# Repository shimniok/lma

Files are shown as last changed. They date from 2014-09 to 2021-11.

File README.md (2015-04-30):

lma
===
Lost Model Alarm for finding your lost aircraft.

[User Guide](https://github.com/shimniok/lma/blob/master/firmware/UserGuide.md)

Ultra Micro park flyer planes like the Hobbyzone Champ or Parkzone UM Corsair are light (~40g) and could be blown downwind and out of sight. That's what happened to my Champ.

LMA's on the market usually have 3-pin servo connectors but these RTF planes don't have a place to plug them.

So I decided to make an ultra-light, standalone LMA. Here it is in its various versions along with firmware.

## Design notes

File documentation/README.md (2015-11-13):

# The umlma User Guide

Lost your aircraft? Don't panic; wait for the beeps! After the *SOS Timer* expires, the Ultra-Micro Lost Model Alarm (umlma) beeps SOS every 10 seconds for many hours until you find your missing aircraft.

Also, umlma beeps W in Morse code after a preset *Flight Timer* expires to remind you to land and recharge your aircraft battery.

Want one? [Buy now on Tindie](https://www.tindie.com/products/bot_thoughts/lost-model-alarm/)

##Features
  * Beeps W to warn you to land and recharge
  * Beeps SOS to help you find your lost plane
  * Configurable *Flight Timer* (5, 10, ... 30 minutes) and *SOS Timer*
  * Ultra light, less than 4g with battery
  * Super-efficient 1mA buzzer delivers 80dbA @ 10cm
  * Powered by compact CR1225 battery with low battery warning

##Powering Up
  * Install a CR1225 battery if one isn't installed yet
  * Short the SWITCH pin headers with supplied shorting block
  * After power up, umlma checks the battery voltage and beeps status (see below)

| Beep | Text | Description |
| --- | --- | --- |
| --- -.- | OK | Battery voltage ok |
| ...---... | SOS | Time to get a new CR1225 battery |

* dit = .
* dah = -

###Voltage Calibration
The umlma is calibrated for the low voltage threshold of ~2.5V after being assembled. The firmware performs auto-calibration on initial startup.

##How It Works
Typical RC plane batteries support flight times from 5-15 minutes and running your LiPo battery down too low will ruin it.

After the *Flight Timer* expires, umlma will start beeping W in Morse Code every 10 seconds to warn you it is time to land.

If you lose your plane, the umlma will start to beep SOS in Morse Code after the *SOS Timer* expires. The *SOS Timer* is automatically set to twice the value of the *Flight Timer*

| Beep | Text | Description |
| --- | --- | --- |
| .-- | W | Flight time warning, time to land |
| ...---... | SOS | Listen for this when looking for your lost plane |

* dit = .
* dah = -

##Setting the Flight Timer
It's easy to configure the *Flight Timer*. 

1. Hold down the pushbutton switch while powering on
2. The umlma will beep out the current Flight Timer (as in the table below)
  * If the current *Flight Timer* is what you want, release the button
  * Or, to increment the timer, keep holding the button another 3 seconds
3. umlma will increment the *Flight Timer* by 5 minutes
4. go to 2.

| Beep | Flight Timer | SOS Timer |
| --- | --- | --- |
| . | 5m | 10m |
| - | 10m | 20m |
| -. | 15m | 30m |
| -- | 20m | 40m |
| --. | 25m | 50m |
| --- | 30m | 60m |

* dit = .
* dah = -

##Recovery
###How Long Does It Beep?
The umlma is designed with the optimum tradeoffs between weight, size, and battery life. The umlma is designed to conserve as much battery power as possible to be devoted to recovery. A new battery should continue beeping for at least 10 hours, based on theoretical calculations. Temperature and battery age and construction will affect its longevity.

###How Loud Is It?
Because of weight and size constraints, the umlma uses a CR1225 battery and 
small, efficient buzzer which delivers 80dBA @ 10cm.  As a result, there is a
limit to how close you have to be to the umlma to hear it beeping.  Consider
getting help from a younger person with better hearing. :)
  
##Larger Battery
Instead of the CR1225, you can connect a larger battery to the VCC (positive) and GND (ground) pins on the board. 

A dedicated battery is best. If you lose your plane after running the flight battery down, there will still be power to run the umlma.

##Remote Switch
If you mount your UMLMA inside your plane, you can install an extension wire from the SWITCH pins to a remote switch outside the plane.

## Questions or Problems?
Contact me (Michael Shimniok) at http://www.bot-thoughts.com for more help

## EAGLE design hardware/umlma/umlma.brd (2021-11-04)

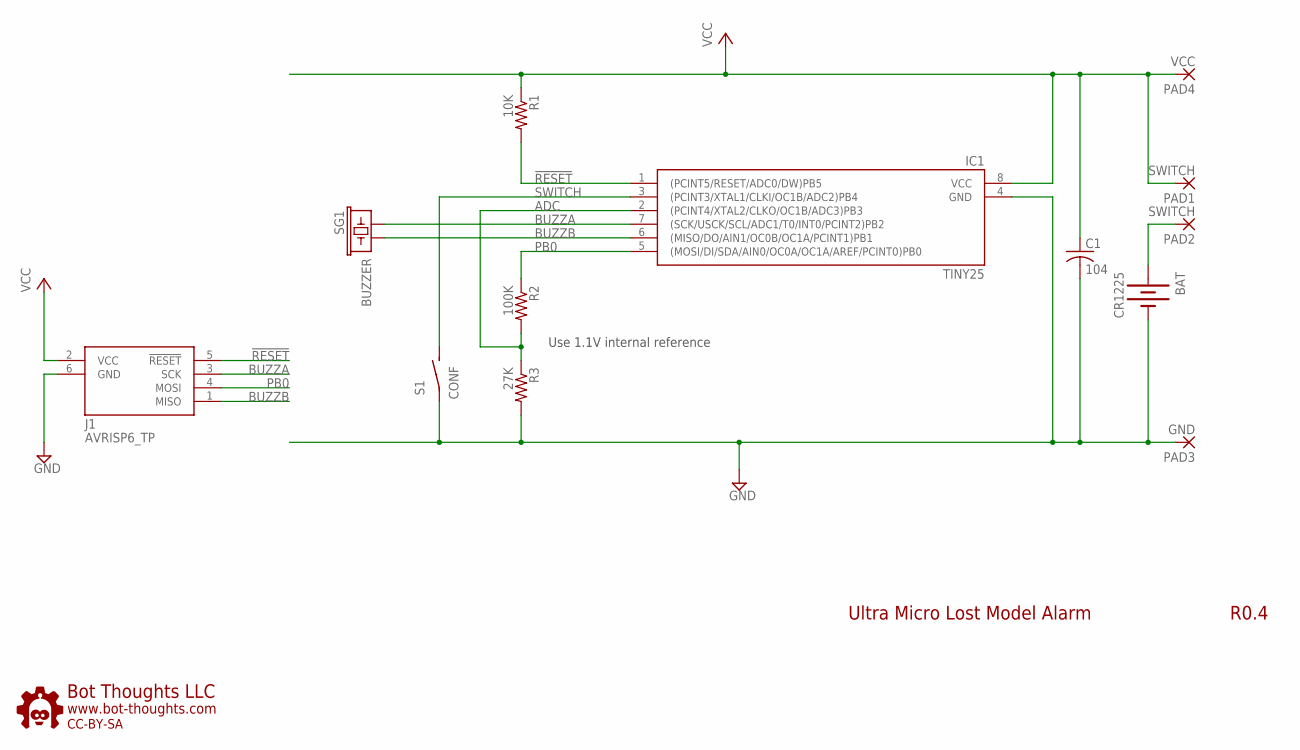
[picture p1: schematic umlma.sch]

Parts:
BAT: CR1225; BATTCON_12MM_PTH
C1: 104; C0603K; PARTNO GRM188R60J105KA01D
IC1: TINY25; SOIC8N
J1: AVRISP6_TP; 2X3_TP
PAD1, PAD2: SWITCH; 1,6/0,8
PAD3: GND; 1,6/0,8
PAD4: VCC; 1,6/0,8
R1: 10K; R0603; PARTNO ERJ-3GEYJ102V
R2: 100K; R0603; PARTNO ERJ-3GEYJ102V
R3: 27K; R0603; PARTNO ERJ-3GEYJ102V
S1: CONF; 3X4X2TACT
SG1: BUZZER; BUZZER_14MM_V_PTH; PARTNO AT-1438-TWT-R
U$1: BTLOGO-LOGO-SM; BTLOGOS

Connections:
!RESET: IC1.1 ((PCINT5/RESET/ADC0/DW)PB5), J1.5 (!RESET), R1.2
ADC: IC1.2 ((PCINT4/XTAL2/CLKO/OC1B/ADC3)PB3), R2.2, R3.1
BUZZA: IC1.7 ((SCK/USCK/SCL/ADC1/T0/INT0/PCINT2)PB2), J1.3 (SCK), SG1.P$5 (1)
BUZZB: IC1.6 ((MISO/DO/AIN1/OC0B/OC1A/PCINT1)PB1), J1.1 (MISO), SG1.P$6 (2)
GND: BAT.GND (-), C1.2, IC1.4 (GND), J1.6 (GND), PAD3.1, R3.2, S1.P$1
unnamed: BAT.VCC@1 (+), PAD2.1
PB0: IC1.5 ((MOSI/DI/SDA/AIN0/OC0A/OC1A/AREF/PCINT0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), J1.4 (MOSI), R2.1
SWITCH: IC1.3 ((PCINT3/XTAL1/CLKI/OC1B/ADC2)PB4), S1.P$2 (S)
VCC: C1.1, IC1.8 (VCC), J1.2 (VCC), PAD1.1, PAD4.1, R1.1

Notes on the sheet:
Ultra Micro Lost Model Alarm
R0.4
Use 1.1V internal reference

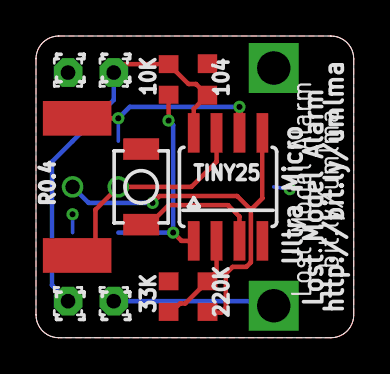
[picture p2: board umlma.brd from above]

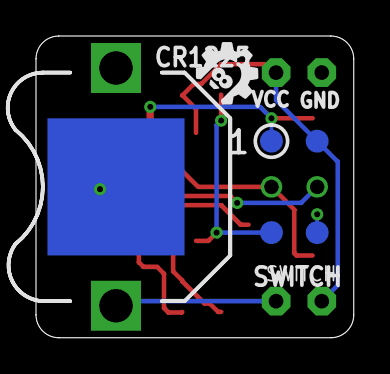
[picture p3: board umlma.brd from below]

Board: 2 copper layers, 17.7 x 16.8 mm, 14 parts (3 on the bottom side), 9 nets.

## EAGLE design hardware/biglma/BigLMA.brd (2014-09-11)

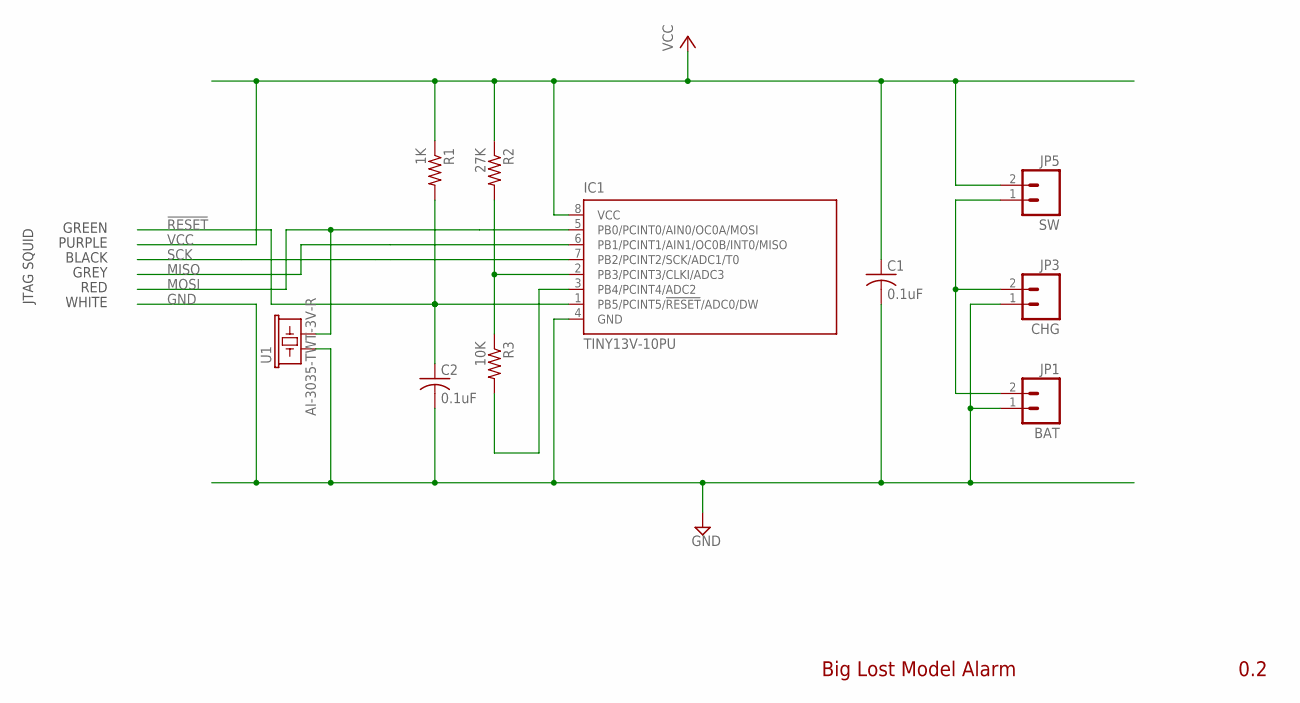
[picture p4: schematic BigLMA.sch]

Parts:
C1, C2: 0.1uF; C0603; PARTNO GRM188R60J105KA01D
IC1: TINY13V-10PU; DIL08; PARTNO ATTINY13V-10PU
JP1: BAT; JST-2-PTH
JP3: CHG; 1X02
JP5: SW; 1X02
R1: 1K; R0603; PARTNO ERJ-3GEYJ102V
R2: 27K; R0603; PARTNO RR0816P-273-D
R3: 10K; R0603; PARTNO RR0816P-103-D
U1: AI-3035-TWT-3V-R; BUZZER-30MM_PTH; PARTNO AI-3035-TWT-3V-R

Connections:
!RESET: C2.1, IC1.1 (PB5/PCINT5/!RESET!/ADC0/DW), R1.2
GND: C1.2, C2.2, IC1.4 (GND), JP1.1, JP3.1, U1.P$1 (1)
MISO: IC1.6 (PB1/PCINT1/AIN1/OC0B/INT0/MISO)
MOSI: IC1.5 (PB0/PCINT0/AIN0/OC0A/MOSI), U1.P$2 (2)
unnamed: IC1.2 (PB3/PCINT3/CLKI/ADC3), R2.2, R3.1
unnamed: JP1.2, JP3.2, JP5.1
unnamed: IC1.3 (PB4/PCINT4/ADC2), R3.2
SCK: IC1.7 (PB2/PCINT2/SCK/ADC1/T0)
VCC: C1.1, IC1.8 (VCC), JP5.2, R1.1, R2.1

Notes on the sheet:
WHITE
RED
GREY
BLACK
PURPLE
GREEN
JTAG SQUID
Big Lost Model Alarm
0.2

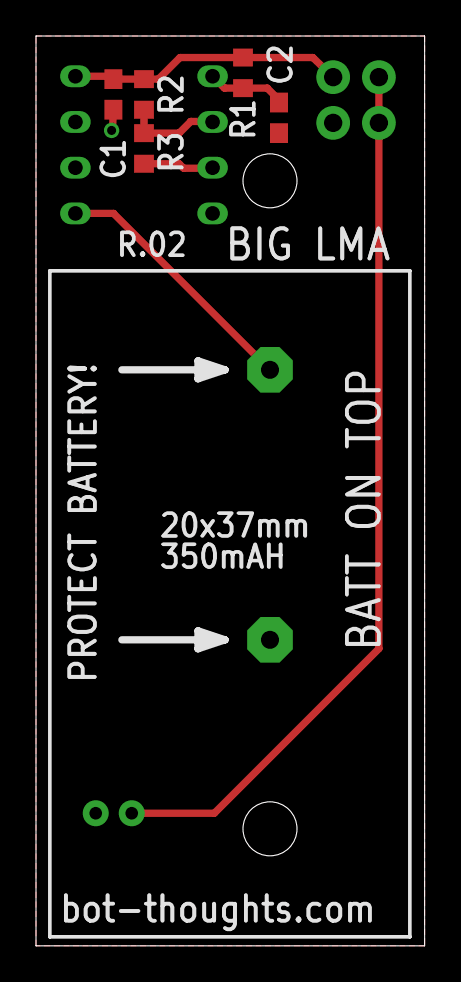
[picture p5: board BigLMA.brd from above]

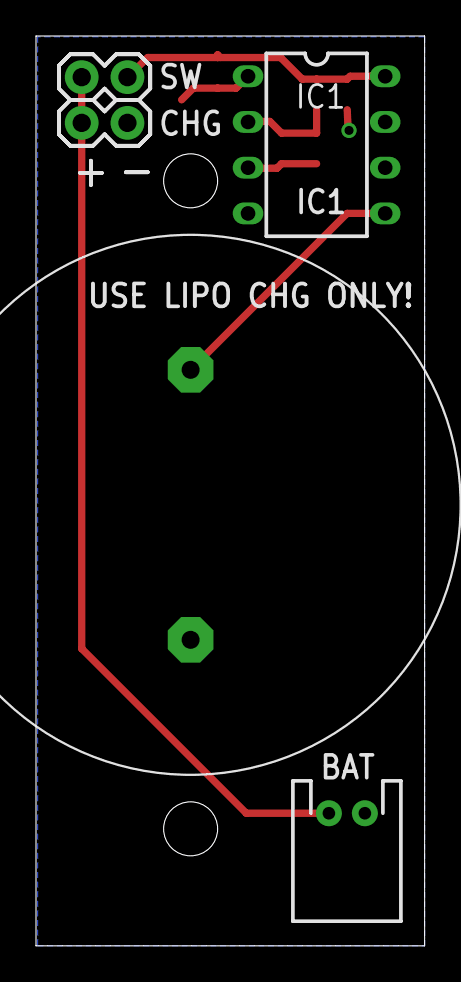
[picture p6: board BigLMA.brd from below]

Board: 2 copper layers, 21.6 x 50.5 mm, 11 parts (5 on the bottom side), 7 nets.

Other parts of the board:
U$1: LIPO_20X37

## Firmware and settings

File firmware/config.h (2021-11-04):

#ifndef _CONFIG_H
#define _CONFIG_H

//#define DEBUG 1

#define BUZZA   PB1     // ATtiny25 Pin 6
#define BUZZB   PB2     // ATtiny25 Pin 7
#define SWITCH  PB4     // ATtiny25 Pin 3
#define LED     PB0     // ATtiny25 Pin 5
#define ADC     PB3     // ATtiny25 Pin 2
#define ADC_EN  PB0     // ATtiny25 Pin 5

#define WARN_PERIOD      10   // Delay period between signal (seconds) -- initial period
#define WARN_PERIOD_LOW  60   // If battery voltage is low, use longer period between beeps
#define BATT_PERIOD     600   // Time in seconds between checking battery voltage

#endif

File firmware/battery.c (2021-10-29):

#include "config.h"
#include "clock.h"
#include <avr/io.h>
#include <util/delay.h>
#include <avr/eeprom.h>
#include "battery.h"

/** battery.c
 *
 * The lma warns the user on startup when the battery falls below ~2.5V
 *
 * Circuit
 * -------
 * The lma is set up to feed a voltage divider with one pin (PB0), and read the divided
 * value with the other (PB3, ADC3). We have to use the internal voltage reference.
 * which varies from 1.0V to 1.2V. Also, the resistors in the divider are 5% tolerance.
 *
 * Calibration
 * -----------
 * That's a pretty huge error which requires calibration. Automatic calibration is
 * done when the lma first starts up (in initADC()) after its eeprom is erased
 * (set to 0).
 *
 * To calibrate, it reads the current voltage, which must be set to 5.0V (within 1%)
 * The adc value returned is 2x that of the 2.5V threshold.  So to get the 2.5V ADC
 * value, right shift the result, then store store it in the threshold eeprom location.
 *
 * Next time initADC() is called, it'll read the threshold and use that.
 *
 * Using
 * -----
 * To erase the calibration, just recompile, and program the eeprom with the .eep file
 * generated at compile time.
 *
 * Note that we want to preserve EEPROM so set Fuses EESAVE and BODLEVEL=1.8V
 */

EEMEM uint16_t cfg_threshold = 0;	// create .eep with this loc initialized to 0.
static uint16_t threshold = 0;      // threshold

uint8_t pinToMux(uint8_t pin) {
	uint8_t mux = 0;
	switch (pin) {
		case PB5: // ADC0
			mux = 0b0000;
			break;
		case PB2: // ADC1
			mux = 0b0001;
			break;
		case PB4: // ADC2
			mux = 0b0010;
			break;
		case PB3: // ADC3
			mux = 0b0011;
			break;
	}
	return mux;
}

void init_battery_thresh() {
	// Read the threshold ADC value for low battery warning
	threshold = eeprom_read_word(&cfg_threshold);

	// Auto-calibrate battery warning threshold.
	// Zero out threshold location in eeprom.
	// Then, start MCU with Vcc=5.0V
	if (threshold == 0) {
		// Get voltage (stored in volts)
		// Divide result by 2 to get 2.5V
		threshold = getVoltage() / 2;
		// Store the new threshold in eeprom
		eeprom_update_word(&cfg_threshold, threshold);
	}
}


void adc_on() {
	// internal 1.1V reference, select ADC pin
	ADMUX = (1<<REFS1)| 0b011; // TODO: convert to defines
	// Take ADC out of shutdown and clear left adjust register
	ADCSRA |= (1<<ADEN);
	ADCSRA &= ~(1<<ADLAR);
}

void adc_off() {
	// Disable ADC
	ADCSRA &= ~(1<<ADEN);
}

uint8_t ddrb;

void divider_on() {
	// enable voltage divider
	ddrb = DDRB;
	DDRB |= _BV(ADC_EN);
	PORTB |= _BV(ADC_EN);
}

void divider_off() {
	PORTB &= ~_BV(ADC_EN);
	DDRB = ddrb;
}

/**
 * Read battery voltage, compare to threshold value representing 2.5V which is
 * about where the CR1225 battery is at its end.
 */
uint16_t getVoltage()
{
	uint8_t i;

	divider_on();
	adc_on();

	// Read voltage, multiple samples w/ delay between each
	uint16_t sum = 0;
	for (i = 0; i < 16; i++) {
		// start conversion
		ADCSRA |= (1<<ADSC);
		// wait for result
		while ((ADCSRA & _BV(ADIF)) == 0x0);
		sum += ADCL;
		sum += ADCH<<8;
		// reset ADIF
		ADCSRA |= _BV(ADIF);
		// wait around for a little while
		wait_ms(10);
	}
	uint16_t avg = sum / 16;

	adc_off();

	// ADC = Vin * 1024 / Vref
	// Vin = (1024 / 1.1) / ADC result
	// x 1000 for 3 digits of precision
	uint16_t volts = (1100UL * avg) / 1024UL;

	divider_off();

	return volts;
}

/**
 * return the most recently read Voltage
 */
uint8_t checkVoltage() {
	return (getVoltage() > threshold);
}

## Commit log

2014-09-11 converting to git
    [BigLMA.brd, BigLMA.sch, BigLMA_2.brd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]
2014-09-11 Renamed LMA to UMLMA
    [UM_LMA.brd, UM_LMA.sch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]
2014-12-02 added adc files from big lma
2014-12-02 Added voltage call / beep
2014-12-03 Modified adc.c to convert based on 3V coin battery and umlma voltage divider (220k/100k)
2014-12-03 Modified code to simply check if volts < 2.6V and warn otherwise beep ok
2014-12-03 added buzzer module, redefined beepOn() and beepOff() as functions to save space
    [buzzer.c, buzzer.h, config.h]
2014-12-04 Added battery low voltage warning on startup with auto-calibration
2014-12-04 renamed adc.* to battery.*, renamed UM_LMA.c to lma.c
2014-12-04 added ADC shutdown for t13a
2014-12-04 Removed VOLT_LOW which is now unused
2014-12-04 corrected pins for controlling voltage divider, measuring voltage. Oops.
    [battery.c]
2014-12-04 Modified schematic and board to reflect hardware changes required for low voltage detection
    [UM_LMA.brd, UM_LMA.sch]
2014-12-04 starting to convert to tiny25, config button, trying to re-do layout
    [UM_LMA.brd, UM_LMA.sch]
2014-12-12 Revised PCB layout, reduced board length.
    [UM_LMA.brd, UM_LMA.sch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]
2014-12-12 Updated silkscreen
    [UM_LMA.brd]
2014-12-12 fixed batt/isp interference, revised layout again, revised board size, modified silk
    [UM_LMA.brd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]
2014-12-12 revised to fix silk conflicts, narrowed silk lines
    [UM_LMA.brd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]
2015-10-20 Updated makefile for ATtiny85 (for now), fuse updates, and dependency added to make target when doing make install
2015-10-20 Added switch module, recomputed F_CPU for ATtiny[248]5 MCU with 8MHz / 64 prescaler, added morse numeric output
2015-10-20 Modified buzzer so output is set low when not beeping and clock is turned off
    [buzzer.c]
2015-10-20 added test to see if switch works, revised switchPressed to simply poll the pin
2015-10-20 Changed logic to increment warning timeout while button is pressed upon reset
2015-10-20 removed duplicate BUZZ definition
    [buzzer.h]
2015-10-20 revised switch to simply debounce and check pin
2015-10-21 fixed ADC settings for tiny25 family
    [battery.c]
2015-10-21 Uncommented startup voltage check
2015-10-21 commented out diagnostic voltage beeps
2015-10-21 Removed extraneous switch pull-up resistor, moved layout and silk labels, increased switch footprint sizes, updated gerbers
    [UM_LMA.brd, UM_LMA.sch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]
2015-10-21 renamed biglma/umlma directories
    [BigLMA.brd, BigLMA.sch, BigLMA_2.brd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]
2015-10-21 renamed UM_LMA.* files to umlma.*
    [umlma.brd, umlma.sch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]
2015-10-21 Edits to cover setting flight timer and put beeps in table
2015-10-21 added warning to remove cr1225 with external battery
2015-11-10 put warning time beep count into subroutine in morse.c; changed switch pressed logic to check at startup, before entering loop and within loop
2015-11-13 enabled internal pull-up on switch due to hardware change eliminating external pullup
2021-10-25 pin assigns, pause to program, buzz w/ 2 pins 2x voltage
    [buzzer.c, config.h]
2021-10-25 fix compile issues with interrupt vectors
    [buzzer.c]
2021-10-25 added fuses dep on all
2021-10-25 remove buzzer init, other minor tweaks
    [buzzer.c, buzzer.h]
2021-10-25 revise mcu pin assignments
    [umlma.brd, umlma.sch]
2021-10-26 config for timer0 in .h, use prescaler
2021-10-26 improved clock/timer parameterization
2021-10-26 updated package to correct labeling error
    [umlma.brd, umlma.sch]
2021-10-26 fixed adc conversion for batt volt measurement
    [battery.c, config.h]
2021-10-29 speed up battery voltage check
2021-10-29 updates to schematic & layout
    [umlma.brd, umlma.sch]
2021-10-29 fixed battery check timing
2021-11-04 updated layout, silk, gerbers, zip
    [umlma.brd, umlma.sch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]

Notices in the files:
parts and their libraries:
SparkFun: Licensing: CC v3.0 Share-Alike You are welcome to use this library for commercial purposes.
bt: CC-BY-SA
